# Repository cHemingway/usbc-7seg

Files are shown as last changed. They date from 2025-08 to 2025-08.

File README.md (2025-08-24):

## USB-C Seven Seg
A USB-C controlled seven segment display, to try out some really tiny SMD 7 seg displays

Designed to be assembled by JLCPCB, using basic parts where possible

Uses a WCH [CH32V203 micro](https://github.com/openwch/ch32v20x) as its small, cheap, has USB 

Credit to Adafruit for the idea of hiding the programming pads on the other side of the USB-C connector

### TODO
- Work out why JLCPCB assembly is so pricy. Maybe this needs to be single sided?
- Check footprint for USB-C connector
- Maybe tidy up the routing, its quite vibe/push-n-shove currently
- Order Rev1 and bring up
- Think of firmware API. USB-CDC, `2.0 <enter>` seems good for now
- Write the firmware

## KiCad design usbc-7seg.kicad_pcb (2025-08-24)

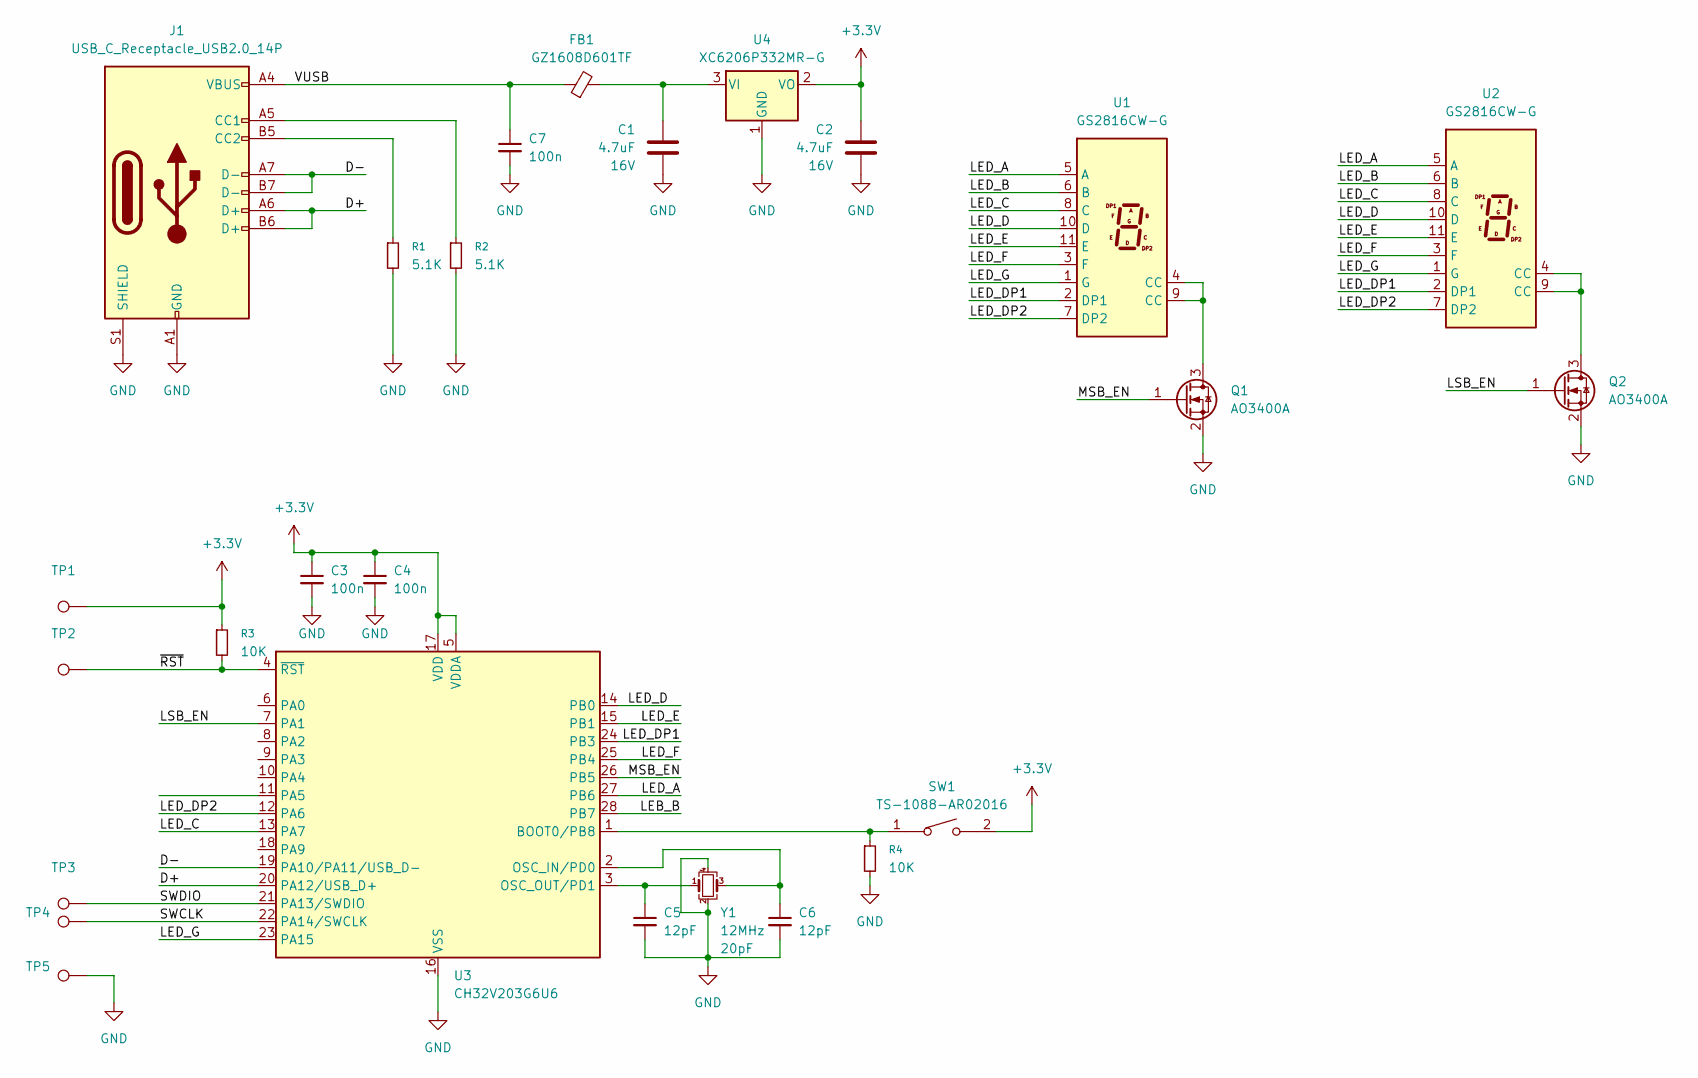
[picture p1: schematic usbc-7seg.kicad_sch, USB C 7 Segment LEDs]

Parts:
C1, C2: 4.7uF; C_0603_1608Metric; Voltage 16V; LCSC PN C19666
C3, C4, C7: 100n; C_0402_1005Metric; LCSC PN C1525
C5, C6: 12pF; C_0402_1005Metric; LCSC PN C1547
FB1: GZ1608D601TF; L_0603_1608Metric; LCSC PN C1002
J1: USB_C_Receptacle_USB2.0_14P; USB_C_Receptacle_HCTL_HC-TYPE-C-16P-01A
Q1, Q2: AO3400A; SOT-23; LCSC PN C20917
R1, R2: 5.1K; R_0402_1005Metric; LCSC PN C25905
R3, R4: 10K; R_0402_1005Metric; LCSC PN C25744
SW1: TS-1088-AR02016; SW-SMD_L3.9-W3.0-P4.45; LCSC PN C720477
TP1, TP2, TP3, TP4, TP5: TestPoint_Pad_D1.5mm
U1, U2: GS2816CW-G; GS2816ACX-X; LCSC PN C22462653
U3: CH32V203G6U6; WQFN-28-1EP_4x4mm_P0.4mm_EP2.7x2.7mm; LCSC PN C5142280
U4: XC6206P332MR-G; SOT-23-3; LCSC PN C5446
Y1: 12MHz; Crystal_SMD_3225-4Pin_3.2x2.5mm; LCSC PN C9002

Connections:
+3.3V: C2.1, C3.1, C4.1, R3.1, SW1.2, TP1.1, U3.5 (VDDA), U3.17 (VDD), U4.2 (VO)
/D+: J1.A6 (D+), J1.B6 (D+), U3.20 (PA12/USB_D+)
/D-: J1.A7 (D-), J1.B7 (D-), U3.19 (PA10/PA11/USB_D-)
/LEB_B: U3.28 (PB7)
/LED_A: U1.5 (A), U2.5 (A), U3.27 (PB6)
/LED_B: U1.6 (B), U2.6 (B)
/LED_C: U1.8 (C), U2.8 (C), U3.13 (PA7)
/LED_D: U1.10 (D), U2.10 (D), U3.14 (PB0)
/LED_DP1: U1.2 (DP1), U2.2 (DP1), U3.24 (PB3)
/LED_DP2: U1.7 (DP2), U2.7 (DP2), U3.12 (PA6)
/LED_E: U1.11 (E), U2.11 (E), U3.15 (PB1)
/LED_F: U1.3 (F), U2.3 (F), U3.25 (PB4)
/LED_G: U1.1 (G), U2.1 (G), U3.23 (PA15)
/LSB_EN: Q2.1 (G), U3.7 (PA1)
/MSB_EN: Q1.1 (G), U3.26 (PB5)
/SWCLK: TP4.1, U3.22 (PA14/SWCLK)
/SWDIO: TP3.1, U3.21 (PA13/SWDIO)
/VUSB: C7.1, FB1.1, J1.A4 (VBUS), J1.A9 (VBUS), J1.B4 (VBUS), J1.B9 (VBUS)
/~RST: R3.2, TP2.1, U3.4 (~RST)
GND: C1.2, C2.2, C3.2, C4.2, C5.2, C6.2, C7.2, J1.A1 (GND), J1.A12 (GND), J1.B1 (GND), J1.B12 (GND), J1.S1 (SHIELD), Q1.2 (S), Q2.2 (S), R1.2, R2.2, R4.2, TP5.1, U3.16 (VSS), U3.29 (VSS), U4.1 (GND), Y1.2, Y1.4
unnamed: J1.A5 (CC1), R2.1
unnamed: J1.B5 (CC2), R1.1
unnamed: Q1.3 (D), U1.4 (CC), U1.9 (CC)
unnamed: Q2.3 (D), U2.4 (CC), U2.9 (CC)
unnamed: R4.1, SW1.1, U3.1 (BOOT0/PB8)
unnamed: C6.1, U3.2 (OSC_IN/PD0), Y1.3
unnamed: C5.1, U3.3 (OSC_OUT/PD1), Y1.1
unnamed: C1.1, FB1.2, U4.3 (VI)

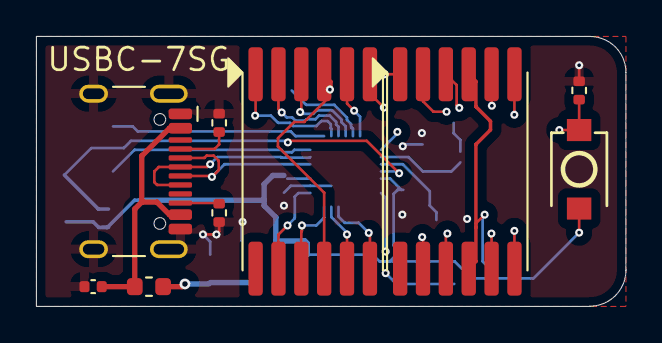
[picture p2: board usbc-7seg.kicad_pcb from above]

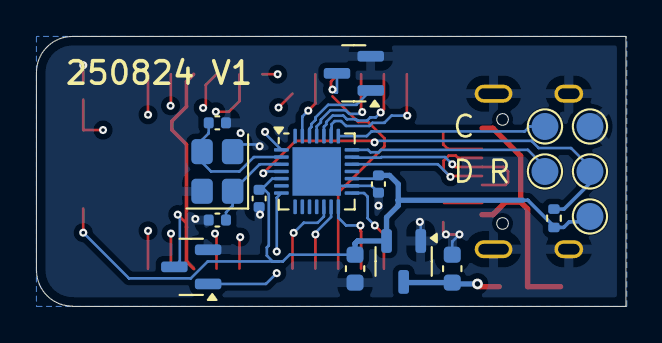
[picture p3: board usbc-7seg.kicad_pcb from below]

Board: 4 copper layers, 32.8 x 15.0 mm, 26 parts (17 on the bottom side), 27 nets.

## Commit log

2025-08-23 Initial commit, draft schematic + floorplan
    [usbc-7seg.kicad_pcb, usbc-7seg.kicad_sch]
2025-08-23 Some routing, setup board stackup properly
    [usbc-7seg.kicad_pcb, usbc-7seg.kicad_sch]
2025-08-24 Routing complete, DRC todo
    [usbc-7seg.kicad_pcb]
2025-08-24 Passing DRC
    [usbc-7seg.kicad_pcb]
2025-08-24 Fix USB-C CC resistors
    [usbc-7seg.kicad_pcb, usbc-7seg.kicad_sch]
2025-08-24 First gerber export
    [usbc-7seg-B_Cu.gbl, usbc-7seg-B_Mask.gbs, usbc-7seg-B_Paste.gbp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]
2025-08-24 Change to use Fabrication Toolkit for export
    [usbc-7seg-B_Cu.gbl, usbc-7seg-B_Mask.gbs, usbc-7seg-B_Paste.gbp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]
2025-08-24 Add JLCPCB part numbers for all parts
    [usbc-7seg.kicad_pcb, usbc-7seg.kicad_sch]
